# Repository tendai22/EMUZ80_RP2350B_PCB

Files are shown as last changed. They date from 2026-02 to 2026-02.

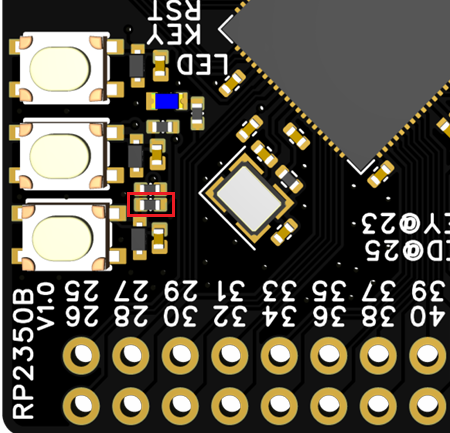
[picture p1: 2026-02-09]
img/002-RP2350-Core-Board-remove-51kohm.png

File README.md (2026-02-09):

# EMUZ80_RP2350B_PCB

KiCad PCB for EMUZ80 for WeAct RP2350B CoreBoard

## What is this.

RP2350B CoreBoard ベースの Z80 基板を手配線で作成し、ソフトを開発してきたが、そろそろ使い方が固まってきたので、RP2350B Core Board ベースで8bit CPU 駆動ソフト開発用の基板を作れそうな気がしたので、基板を1枚起こした。

6502駆動のために、メモリマップドI/Oのためのアドレスデコードも試そうと、GPIO16 に WAIT を割り当て、その上3本を空けてある。ファームがまだできていないので検証はまだだが、多分大丈夫。

AE-RP2040 基板で搭載した、ジャンパ飛ばし端子は用意できなかった。既存のメザニン基板をそのまま使うことは多分難しいだろう。

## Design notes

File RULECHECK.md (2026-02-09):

# KiCad設定ルール

## 銅

最小クリアランス: 0.127mm OK
最小配線幅: 0.127mm OK
最小接続幅: 0mm
最小アニュラ幅: 0.05mm OK
最小ピア直径: 0.4mm OK
導体から穴のクリアランス: 0.2mm OK
導体から基板端クリアランス: 0.2mm OK

## 穴

最小スルーホール: 0.15mm OK
穴から穴へのクリアランス: 0.45mm OK

## マイクロビア

最小マイクロビア直径: 0.256mm
最小マイクロビア穴径: 0.127mm

## シルクスクリーン

アイテムの最小クリアランス: 0mm
最小テキスト高さ: 0.8mm
最小のテキスト太さ: 0.08mm -> 1.53mm (6mil)

## 穴径

穴径: 0.2mm OK
ビア径: 0.4mm OK

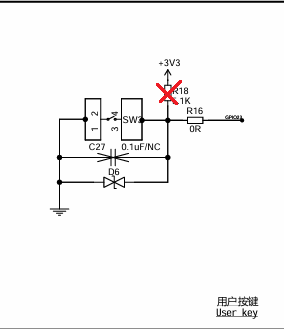
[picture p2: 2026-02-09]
img/001-RP2350-Core-Board-KEY-circuit-anno.png

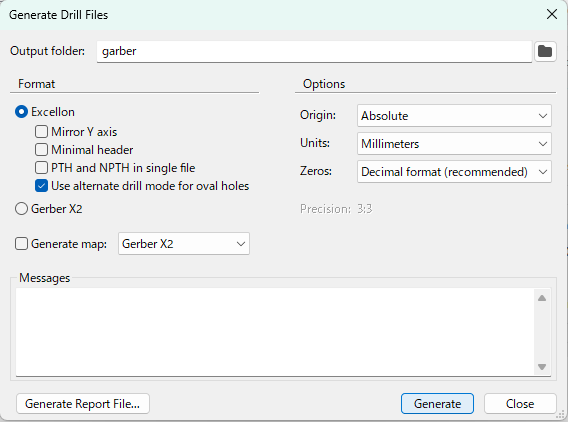
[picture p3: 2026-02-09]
img/GarberGenerateDrillSettingForJLCPCB.png

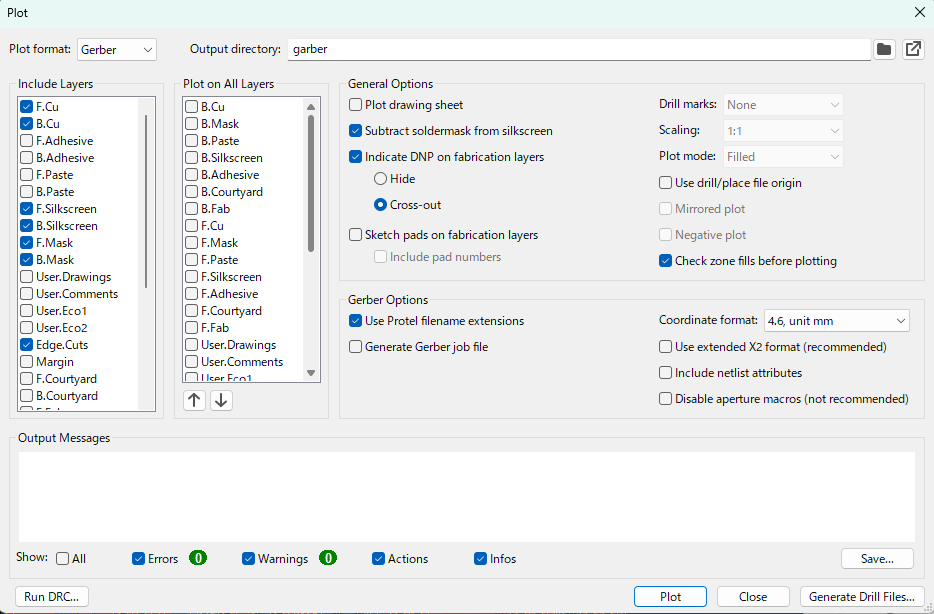
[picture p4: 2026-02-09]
img/GarberGenerateSettingForJLCPCB.png

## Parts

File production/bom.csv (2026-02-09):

Designator | Footprint | Quantity | Value | LCSC Part #
C1, C2, C3, C4, C5 | C_Disc_D3.0mm_W1.6mm_P2.50mm | 5 | 0.1u
C7 | CP_Radial_D5.0mm_P2.50mm | 1 | 10uF
D1, D5 | D_DO-34_SOD68_P7.62mm_Horizontal | 2 | 1S3
D2 | LED_D3.0mm | 1 | RED
D3 | LED_D3.0mm | 1 | GREEN
D4 | LED_D3.0mm | 1 | YELLOW
J3 | PinHeader_1x08_P2.54mm_Vertical | 1 | EXT_GPIO1
J4 | PinHeader_1x02_P2.54mm_Vertical | 1 | EXT_GPIO2
J5 | PinHeader_1x06_P2.54mm_Horizontal_NoFeet | 1 | Serial
J6 | USB_Micro-B_Hirose_ZX62-B-5PA | 1 | USB_B_Micro
J8 | PinHeader_1x05_P2.54mm_Vertical | 1 | Conn_01x05_Pin
JP1 | SolderJumper-2_P1.3mm_Bridged_RoundedPad1.0x1.5mm | 1 | VCC_Jumper
JP2 | SolderJumper-2_P1.3mm_Bridged_RoundedPad1.0x1.5mm | 1 | CE1_J
JP3 | SolderJumper-2_P1.3mm_Bridged_RoundedPad1.0x1.5mm | 1 | CS2_J
JP4 | SolderJumper-2_P1.3mm_Bridged_RoundedPad1.0x1.5mm | 1 | OE_J
JP5 | SolderJumper-2_P1.3mm_Bridged_RoundedPad1.0x1.5mm | 1 | WE_J
R1, R2, R3 | R_Axial_L5.5mm_D2.0mm_P7.62mm_Horizontal | 3 | 1k
R4 | R_Axial_L5.5mm_D2.0mm_P7.62mm_Horizontal | 1 | 10k
SW1 | Tact_SW | 1 | RUN
SW2 | Tact_SW | 1 | BOOTSEL
U1 | PLCC-64_THT-Socket | 1 | Pimoroni PGA2350B
U2 | RB2350B_Core_Board | 1 | RB2350B_Core_Board
U3 | DIP-14_W7.62mm_Socket | 1 | 74HC00
U4 | DIP-40_SidePin_Z80 | 1 | Z80CPU
U5 | DIP-32_W15.24mm_OvalPads | 1 | HM628128

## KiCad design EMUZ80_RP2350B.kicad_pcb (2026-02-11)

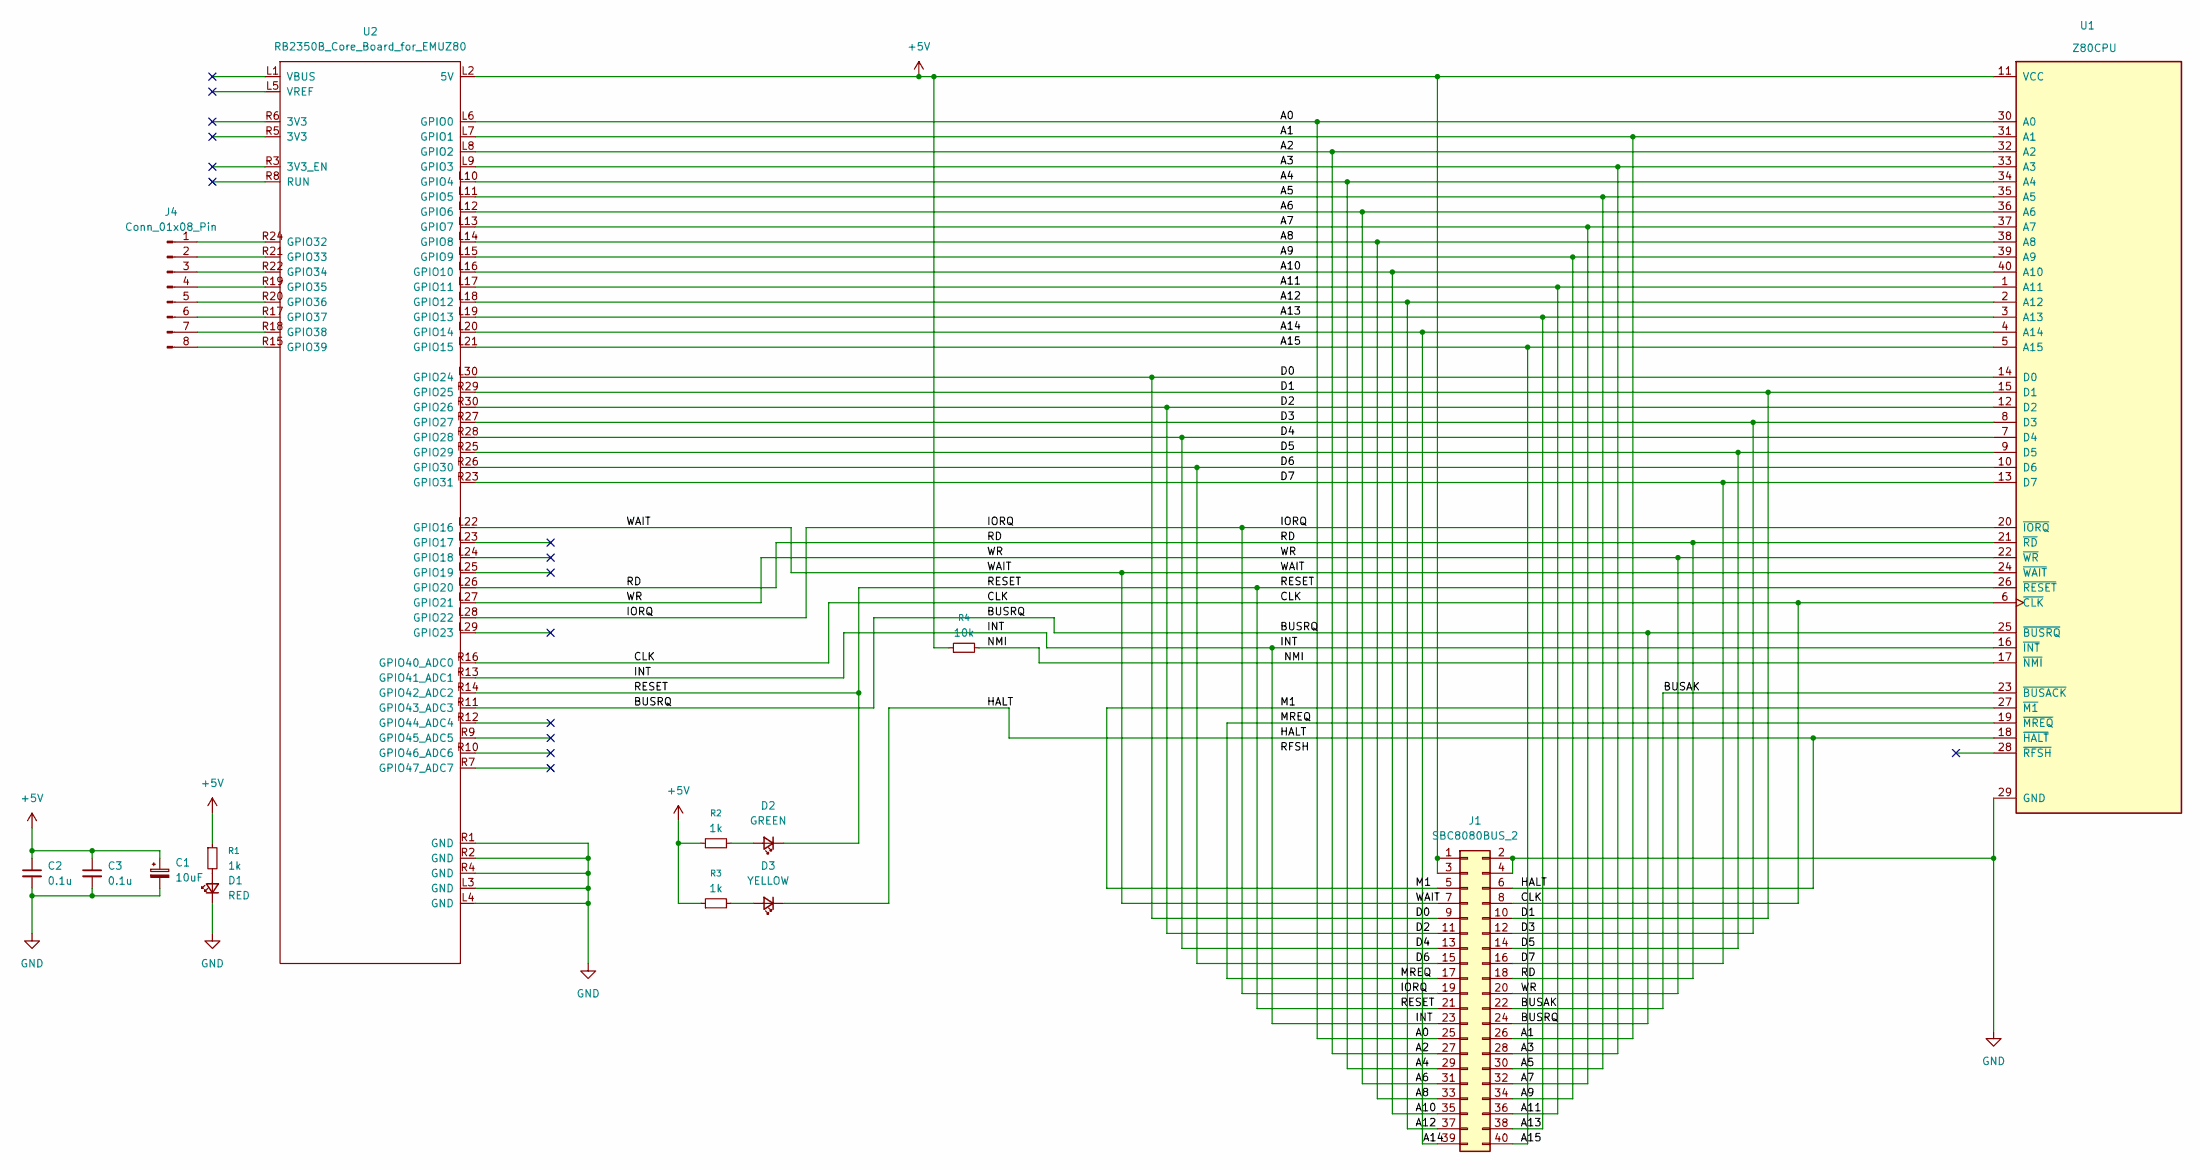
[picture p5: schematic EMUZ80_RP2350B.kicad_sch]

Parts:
C1: 10uF; CP_Radial_D5.0mm_P2.50mm
C2, C3: 0.1u; C_Disc_D3.0mm_W1.6mm_P2.50mm
D1: RED; LED_D3.0mm
D2: GREEN; LED_D3.0mm
D3: YELLOW; LED_D3.0mm
J1: SBC8080BUS_2; PinSocket_2x20_OvalPad
J4: Conn_01x08_Pin; PinHeader_1x08_P2.54mm_Vertical
R1, R2, R3: 1k; R_Axial_L5.5mm_D2.0mm_P7.62mm_Horizontal
R4: 10k; R_Axial_L5.5mm_D2.0mm_P7.62mm_Horizontal
U1: Z80CPU; DIP-40_SidePin_Z80
U2: RB2350B_Core_Board_for_EMUZ80; RB2350B_Core_Board

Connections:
+5V: C1.1, C2.1, C3.1, J1.1 (5V), J1.3 (5V), R1.1, R2.1, R3.1, R4.1, U1.11 (VCC), U2.L2 (5V)
/A0: J1.25 (A0), U1.30 (A0), U2.L6 (GPIO0)
/A1: J1.26 (A1), U1.31 (A1), U2.L7 (GPIO1)
/A2: J1.27 (A2), U1.32 (A2), U2.L8 (GPIO2)
/A3: J1.28 (A3), U1.33 (A3), U2.L9 (GPIO3)
/A4: J1.29 (A4), U1.34 (A4), U2.L10 (GPIO4)
/A5: J1.30 (A5), U1.35 (A5), U2.L11 (GPIO5)
/A6: J1.31 (A6), U1.36 (A6), U2.L12 (GPIO6)
/A7: J1.32 (A7), U1.37 (A7), U2.L13 (GPIO7)
/A8: J1.33 (A8), U1.38 (A8), U2.L14 (GPIO8)
/A9: J1.34 (A9), U1.39 (A9), U2.L15 (GPIO9)
/A10: J1.35 (A10), U1.40 (A10), U2.L16 (GPIO10)
/A11: J1.36 (A11), U1.1 (A11), U2.L17 (GPIO11)
/A12: J1.37 (A12), U1.2 (A12), U2.L18 (GPIO12)
/A13: J1.38 (A13), U1.3 (A13), U2.L19 (GPIO13)
/A14: J1.39 (A14), U1.4 (A14), U2.L20 (GPIO14)
/A15: J1.40 (A15), U1.5 (A15), U2.L21 (GPIO15)
/BUSAK: J1.22 (BUSAK), U1.23 (~BUSACK)
/BUSRQ: J1.24 (BUSRQ), U1.25 (~BUSRQ), U2.R11 (GPIO43_ADC3)
/CLK: J1.8 (CLK), U1.6 (~CLK), U2.R16 (GPIO40_ADC0)
/D0: J1.9 (D0), U1.14 (D0), U2.L30 (GPIO24)
/D1: J1.10 (D1), U1.15 (D1), U2.R29 (GPIO25)
/D2: J1.11 (D2), U1.12 (D2), U2.R30 (GPIO26)
/D3: J1.12 (D3), U1.8 (D3), U2.R27 (GPIO27)
/D4: J1.13 (D4), U1.7 (D4), U2.R28 (GPIO28)
/D5: J1.14 (D5), U1.9 (D5), U2.R25 (GPIO29)
/D6: J1.15 (D6), U1.10 (D6), U2.R26 (GPIO30)
/D7: J1.16 (D7), U1.13 (D7), U2.R23 (GPIO31)
/HALT: D3.1 (K), J1.6 (NC), U1.18 (~HALT)
/INT: J1.23 (INT), U1.16 (~INT), U2.R13 (GPIO41_ADC1)
/IORQ: J1.19 (IORQ), U1.20 (~IORQ), U2.L28 (GPIO22)
/M1: J1.5 (M1), U1.27 (~M1)
/MREQ: J1.17 (MREQ), U1.19 (~MREQ)
/NMI: R4.2, U1.17 (~NMI)
/RD: J1.18 (RD), U1.21 (~RD), U2.L26 (GPIO20)
/RESET: D2.1 (K), J1.21 (RESET), U1.26 (~RESET), U2.R14 (GPIO42_ADC2)
/WAIT: J1.7 (WAIT), U1.24 (~WAIT), U2.L22 (GPIO16)
/WR: J1.20 (WR), U1.22 (~WR), U2.L27 (GPIO21)
GND: C1.2, C2.2, C3.2, D1.1 (K), J1.2 (GND), J1.4 (GND), U1.29 (GND), U2.L3 (GND), U2.L4 (GND), U2.R1 (GND), U2.R2 (GND), U2.R4 (GND)
unnamed: D1.2 (A), R1.2
unnamed: D2.2 (A), R2.2
unnamed: D3.2 (A), R3.2
unnamed: J4.1, U2.R24 (GPIO32)
unnamed: J4.2, U2.R21 (GPIO33)
unnamed: J4.3, U2.R22 (GPIO34)
unnamed: J4.4, U2.R19 (GPIO35)
unnamed: J4.5, U2.R20 (GPIO36)
unnamed: J4.6, U2.R17 (GPIO37)
unnamed: J4.7, U2.R18 (GPIO38)
unnamed: J4.8, U2.R15 (GPIO39)

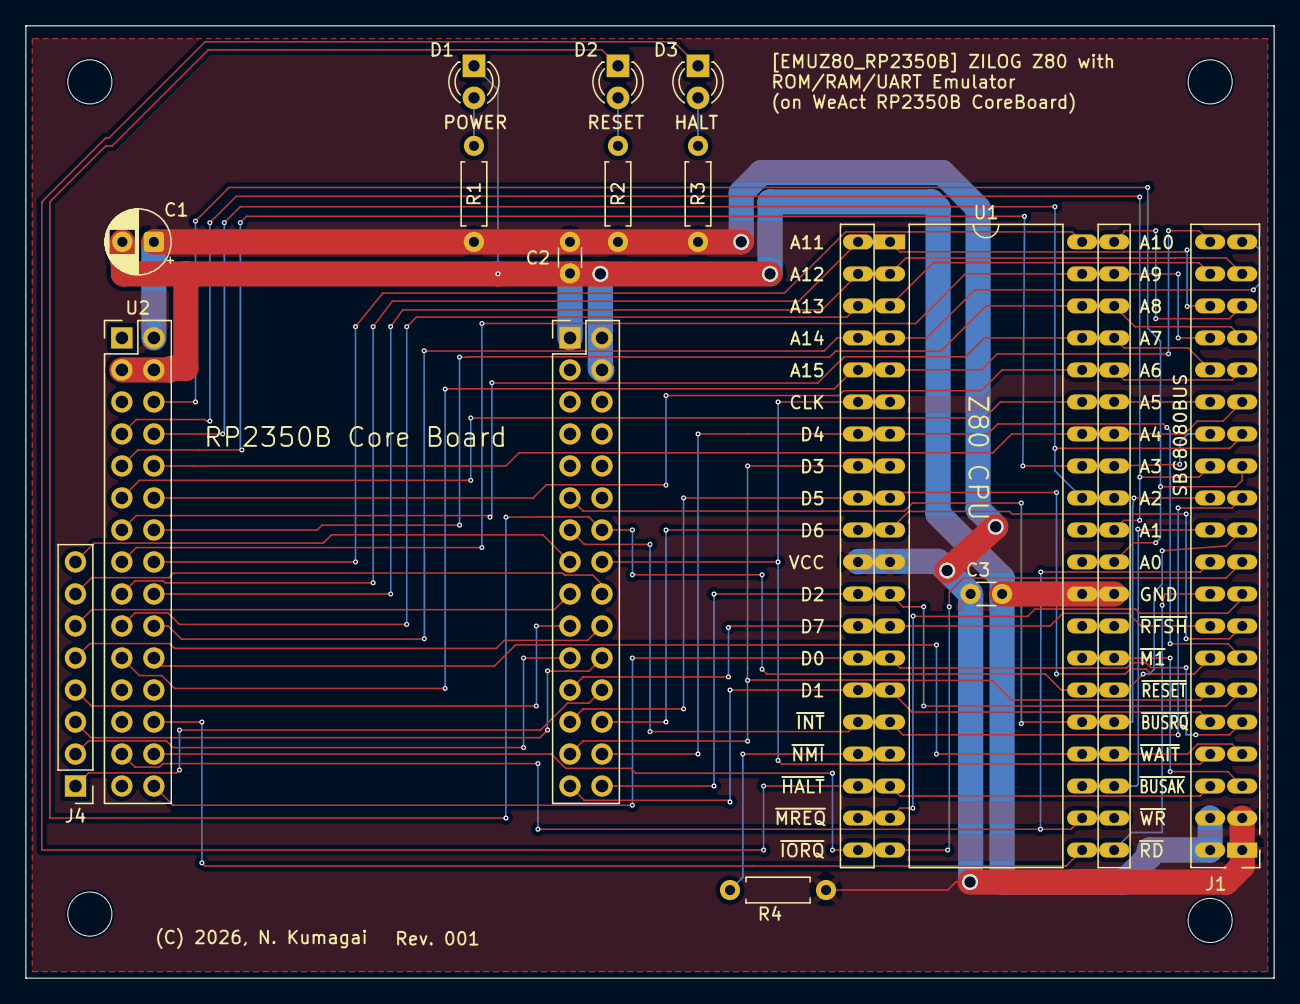
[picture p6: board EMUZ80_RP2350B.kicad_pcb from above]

Board: 2 copper layers, 99.1 x 75.6 mm, 18 parts (0 on the bottom side), 50 nets.

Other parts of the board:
H1, H2, H3, H3#2: MountingHole; MountingHole_3.5mm

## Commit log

2026-02-09 main: Initial commit files, not yet PCBed
    [EMUZ80_RP2350B.kicad_pcb, EMUZ80_RP2350B.kicad_sch, bom.csv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]
2026-02-10 main: Rev001 almost be ready
    [EMUZ80_RP2350B.kicad_pcb, EMUZ80_RP2350B.kicad_sch]
2026-02-11 main: Rev001, ordered now
    [EMUZ80_RP2350B.kicad_pcb]

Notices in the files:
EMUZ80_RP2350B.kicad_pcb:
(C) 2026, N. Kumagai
